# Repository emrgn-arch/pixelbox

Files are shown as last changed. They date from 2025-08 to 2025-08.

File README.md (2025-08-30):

# PixelBox 

<p align="center">
  Short demo
  Side views
</p>

**A modular, standalone pixel-art device** that you can access from any browser on your local network. Built on a Wemos D1 Mini and TFT screen, PixelBox hosts its own web app where you can draw, upload, and paste pixel art that appears live on the display. The included retro-TV enclosure is just one example—you can use the parametric model to design your own housings or adapt the project to different TFT screen sizes.

---

## ✨ Highlights

* **Standalone:** Boots, connects to Wi-Fi, shows its IP, and serves a built-in web UI (no extra apps needed).
* **Modular:** Design and swap enclosures (STEPs + STLs), batteries, or even different TFT screens.
* **Create your way:** Draw pixel-by-pixel, choose colors, clear, paste from the clipboard, or upload images.
* **Fast updates:** A batch RGB drawing API enables quick and responsive rendering while keeping network traffic and MCU load within safe limits.

---

## 🧩 Hardware

* **MCU:** Wemos D1 mini (ESP8266)
* **Display:** 1.44″ ST7735 TFT (compatible variants work)
* **Battery:** \~1000 mAh Li-ion (≈ 40×25×20 mm)
* **Charging:** USB-C Li-ion charger (4.2 V / 1 A)
* **Enclosure:** `hardware/step` (parametric) + `hardware/stl` (printable)

<p align="center">
  Exploded view
</p>

> See `hardware/wiring.png` for a diagram.

⚠️ **Disclaimer:** Working with electronics, batteries, and soldering carries inherent risks. Only attempt wiring, soldering, or battery integration if you have the proper skills and experience. Incorrect handling may result in damage, overheating, or injury. Always follow safe practices and double-check connections before powering the device.

⚡ **Charging Notice:** Use only standard 5V USB power sources (such as a laptop USB port) and avoid fast-charging cables or adapters. The charging module typically indicates status with an onboard LED (commonly red for charging and green/blue for fully charged), but please verify this with your specific component. Never leave the device unattended while charging.

---

## 🛠️ Firmware (PlatformIO)

Requires PlatformIO and these libs (auto-installed via `platformio.ini`):

* Adafruit GFX
* Adafruit ST7735/ST7789
* ArduinoJson
* WiFiManager

Build & upload:

```bash
# From the repo root
pio run -t upload     # compiles and uploads
pio device monitor    # optional: serial logs @ 115200
```

The web interface is defined in `data/index.html`. During the build process, a script inlines it into `include/web_page.h`—no separate SPIFFS upload is required.

`scripts/prebuild.py` is responsible for compressing `data/index.html` and converting embedded images into Base64 format, maximizing storage efficiency and keeping everything self-contained.

---

## ▶️ Use

1. **Power PixelBox.** If it can’t join Wi-Fi, it starts a configuration portal named **MiniPC\_Config**—connect and set your Wi-Fi.

> 💡 To reset or update Wi-Fi credentials later, hold down the button connected to **D6** while powering up the device. This will launch the configuration portal directly.

2. On success, the TFT shows the device IP in your local subnet (e.g., `192.168.1.50`).
3. Open that IP in a browser on the same network. You’ll see a pixel grid UI:

   * Pick colors
   * **Draw** pixels with mous or on touchscreen
   * **Upload** an image or **paste** from clipboard
   * **Clear** the screen, or view **Info**
4. The TFT updates live as you draw, also indicated by blinking LED connected to D3

### API (local)

* `POST /batchDraw` — send batched RGB cell data (JSON)
* `GET /clear` — clear display

---

## 📁 Repo layout

```
src/           # firmware
include/       # generated web_page.h (auto)
scripts/       # prebuild.py (HTML → header)
data/          # index.html + assets (embedded)
hardware/      # STEP/STL + wiring
```

---

## 🧱 Enclosures

The retro-TV housing is one example under `hardware/stl/`. Open the **parametric STEP/Fusion** files in `hardware/step/`, which also includes STEP files of each electronics components. Contributions with new themes welcome!

---

## 🔐 See `LICENSE`

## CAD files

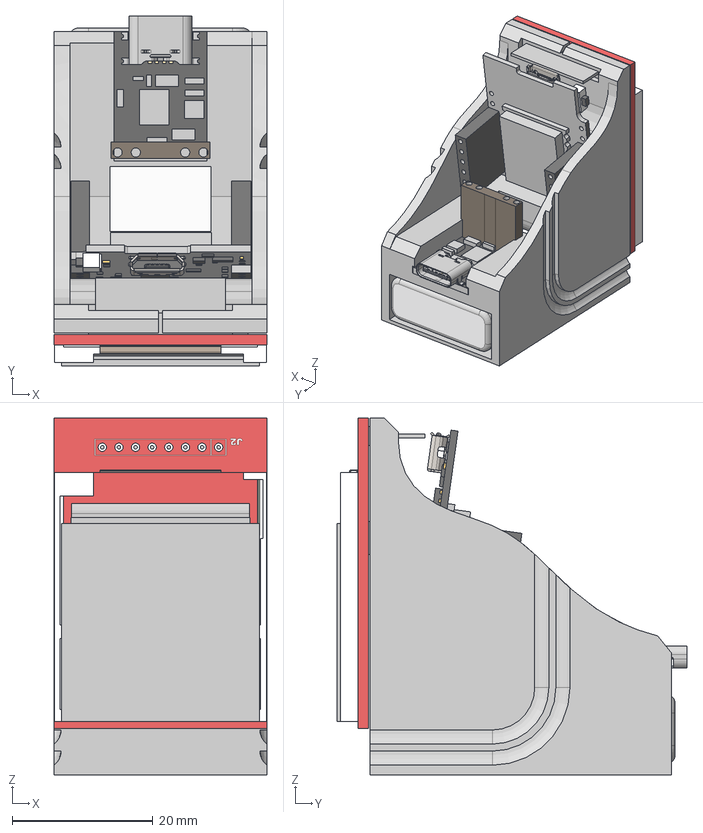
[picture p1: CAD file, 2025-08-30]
hardware/step/Electronics Housing.step
30.2 x 49.7 x 50.7 mm
molex_0473460001
Board
USB C
Li ion 3.7 V Battery
1.44in SPI LCD Module - No Glass

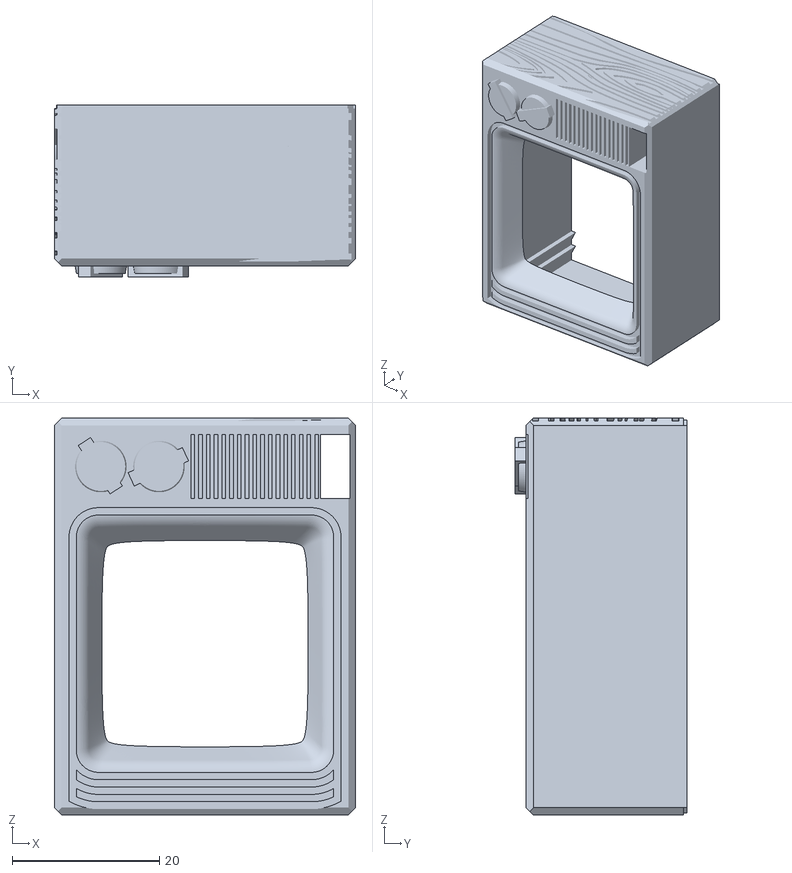
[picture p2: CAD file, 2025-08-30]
hardware/stl/RetroTV_woodenconsole.stl
41.0 x 23.4 x 54.0

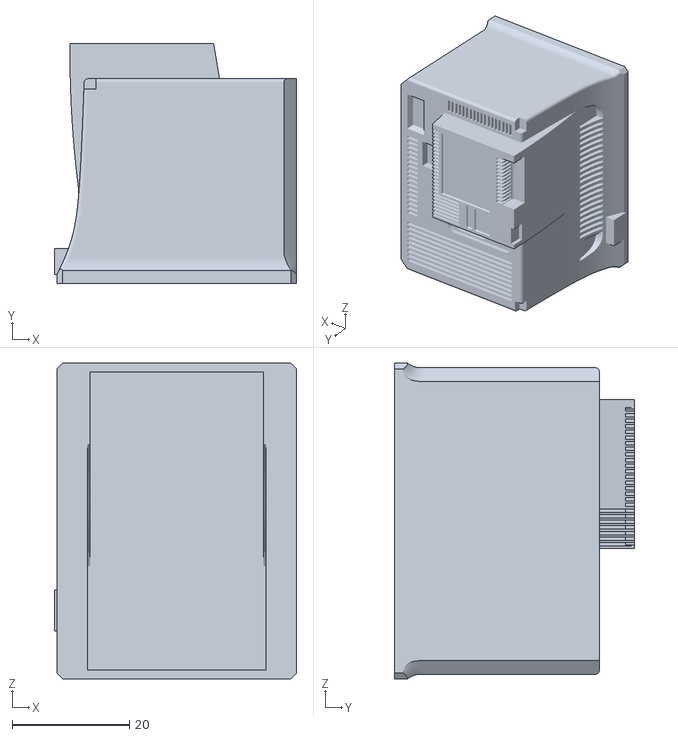
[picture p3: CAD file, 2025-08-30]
hardware/stl/RetroTV_blackcasing.stl
41.4 x 41.0 x 54.0

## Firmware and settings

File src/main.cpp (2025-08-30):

#include <Adafruit_GFX.h>
#include <Adafruit_ST7735.h>
#include <ESP8266WiFi.h>
#include <ESP8266WebServer.h>
#include <WiFiManager.h>
#include <ArduinoJson.h>
#include <EEPROM.h>

#include "web_page.h"

// LEFT-to-RIGHT 3V3 GND D2 D0 D1 D7 D5

// === TFT Display Pins ===
#define TFT_RST   16
#define TFT_CS    4
#define TFT_DC    5
#define RESET_WiFi D6
#define LED_SIGNAL D3

// === Virtual Grid Settings === Calculate this later
const int rows = 43;
const int cols = 43;
const int pixelSize = 3;

// === TFT Instance ===
Adafruit_ST7735 tft(TFT_CS, TFT_DC, TFT_RST);

// === WiFi / EEPROM ===

WiFiManager wm;
ESP8266WebServer server(80);
char ssid[64], pass[64];
bool shouldSaveConfig = false;

// === Save credentials to EEPROM ===
void saveCredentials(const char* newSSID, const char* newPass) {
  for (int i = 0; i < 32; i++) {
    EEPROM.write(i, newSSID[i]);
    EEPROM.write(100 + i, newPass[i]);
  }
  EEPROM.commit();
}

// === Read credentials from EEPROM ===
void readCredentials() {
  for (int i = 0; i < 32; i++) {
    ssid[i] = EEPROM.read(i);
    pass[i] = EEPROM.read(100 + i);
  }
  ssid[31] = '\0';
  pass[31] = '\0';
}

// === Save config callback ===
void saveConfigCallback() {
  shouldSaveConfig = true;
}

// === Draw 1 grid block ===
void drawPixelBlock(int x, int y, uint16_t color) {
  tft.fillRect(x * pixelSize, y * pixelSize, pixelSize, pixelSize, color);
}

// === Draw the grid lines ===
void drawGrid(int cellWidth, int cellHeight, int cols, int rows) {
  for (int y = 1; y < rows; y++)
    tft.drawFastHLine(0, y * cellHeight - 1, cols * cellWidth, ST77XX_BLACK);
  for (int x = 1; x < cols; x++)
    tft.drawFastVLine(x * cellWidth - 1, 0, rows * cellHeight, ST77XX_BLACK);
}

// === Reusable CORS headers ===
void setCORSHeaders() {
  server.sendHeader("Access-Control-Allow-Origin", "*");
  server.sendHeader("Access-Control-Allow-Methods", "POST, OPTIONS, GET");
  server.sendHeader("Access-Control-Allow-Headers", "Content-Type");
}

// === Serve index.html from SPIFFS ===
void handleRoot() {
  setCORSHeaders();
  String html = MAIN_page;  // copy from PROGMEM into RAM
  html.replace("%%IP%%", WiFi.localIP().toString());
  server.send(200, "text/html", html);
}

// === Clear screen ===
void handleClear() {
  setCORSHeaders();
  //tft.fillScreen(ST77XX_BLACK);
  tft.fillScreen(((0x0D & 0xF8) << 8) | ((0x06 & 0xFC) << 3) | (0x02 >> 3));
  server.send(200, "text/plain", "Cleared");
}

// === Handle batch draw JSON ===
void handleBatchDraw() {
  setCORSHeaders();

  analogWrite(LED_SIGNAL, 20);

  if (!server.hasArg("plain")) {
    server.send(400, "text/plain", "Missing JSON payload");
    return;
  }

  const size_t capacity = JSON_ARRAY_SIZE(320) + 320 * JSON_OBJECT_SIZE(5);
  DynamicJsonDocument doc(capacity);

  DeserializationError error = deserializeJson(doc, server.arg("plain"));
  if (error) {
    server.send(400, "text/plain", "JSON parse error");
    return;
  }

  for (JsonObject pixel : doc.as<JsonArray>()) {
    int x = pixel["x"];
    int y = pixel["y"];
    int r = pixel["r"];
    int g = pixel["g"];
    int b = pixel["b"];
    drawPixelBlock(x, y, tft.color565(r, g, b));
  }

  drawGrid(pixelSize, pixelSize, cols, rows);

  analogWrite(LED_SIGNAL, 0);

  server.send(200, "text/plain", "Batch Draw OK");
}

// === WiFi setup (with WiFiManager) ===
void setupWiFi() {
  EEPROM.begin(512);
  pinMode(RESET_WiFi, INPUT_PULLUP);  // Config button

  wm.setSaveConfigCallback(saveConfigCallback);

  if (digitalRead(RESET_WiFi) == LOW) {
    tft.fillScreen(ST77XX_BLACK);
    tft.setTextColor(ST77XX_WHITE);
    tft.setTextSize(1);
    tft.setCursor(0, 0);
    tft.print("Connect WiFi to MiniPC_Config");
    wm.startConfigPortal("MiniPC_Config");
    if (shouldSaveConfig) {
      saveCredentials(wm.getWiFiSSID().c_str(), wm.getWiFiPass().c_str());
      ESP.restart();
    }
  } else {
    readCredentials();
    WiFi.begin(ssid, pass);
    unsigned long startAttempt = millis();
    while (WiFi.status() != WL_CONNECTED && millis() - startAttempt < 10000) {
      delay(500);
      Serial.print(".");
    }

    if (WiFi.status() != WL_CONNECTED) {
      Serial.println("\nFailed to connect, starting config portal...");

      tft.fillScreen(ST77XX_BLACK);
      tft.setTextColor(ST77XX_WHITE);
      tft.setTextSize(1);
      tft.setCursor(0, 0);
      tft.print("Connect WiFi to MiniPC_Config");
      wm.startConfigPortal("MiniPC_Config");     
    
      if (shouldSaveConfig) {
        saveCredentials(wm.getWiFiSSID().c_str(), wm.getWiFiPass().c_str());
        ESP.restart();
      }
    }
  }

  Serial.println("\nWiFi connected: " + WiFi.localIP().toString());

  // Show IP on TFT for 3 seconds
  tft.fillScreen(ST77XX_BLACK);
  tft.setTextColor(ST77XX_WHITE);
  tft.setTextSize(1);
  tft.setCursor(0, 0);
  tft.print("IP Address:");
  tft.setCursor(0, 11);
  tft.print(WiFi.localIP().toString());
  delay(3000); 
  tft.fillScreen(ST77XX_BLACK);
}

// === Setup TFT and SPIFFS ===
void setupTFTAndSPIFFS() {
  tft.initR(INITR_144GREENTAB);
  tft.setRotation(1);
  tft.fillScreen(ST77XX_BLACK);
  drawGrid(pixelSize, pixelSize, cols, rows);
  
}

// === Setup routes ===
void setupWebServer() {
  server.on("/", HTTP_GET, handleRoot);
  server.on("/clear", HTTP_GET, handleClear);

  server.on("/batchDraw", HTTP_OPTIONS, []() {
    setCORSHeaders();
    server.send(204);
  });

  server.on("/batchDraw", HTTP_POST, handleBatchDraw);
  server.begin();
  Serial.println("HTTP server started");
}

void setup() {
  Serial.begin(115200);  
  setupTFTAndSPIFFS();
  setupWiFi();
  setupWebServer();
  pinMode(LED_SIGNAL, OUTPUT); 
}

void loop() {
  server.handleClient();             
}
